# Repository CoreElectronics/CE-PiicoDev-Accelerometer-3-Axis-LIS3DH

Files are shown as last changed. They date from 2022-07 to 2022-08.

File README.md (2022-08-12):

# PiicoDev® Acceleromter LIS3DH

This is the repo for the Core Electronics [PiicoDev Accelerometer LIS3DH](https://core-electronics.com.au/catalog/product/view/sku/CE08705).
(https://core-electronics.com.au/catalog/product/view/sku/CE08705)

## License
This project is open source - please review the LICENSE.md file for further licensing information.

If you have any technical questions, or concerns about licensing, please contact technical support on the [Core Electronics forums](https://forum.core-electronics.com.au/).

*\"PiicoDev\" and the PiicoDev logo are trademarks of Core Electronics Pty Ltd.*

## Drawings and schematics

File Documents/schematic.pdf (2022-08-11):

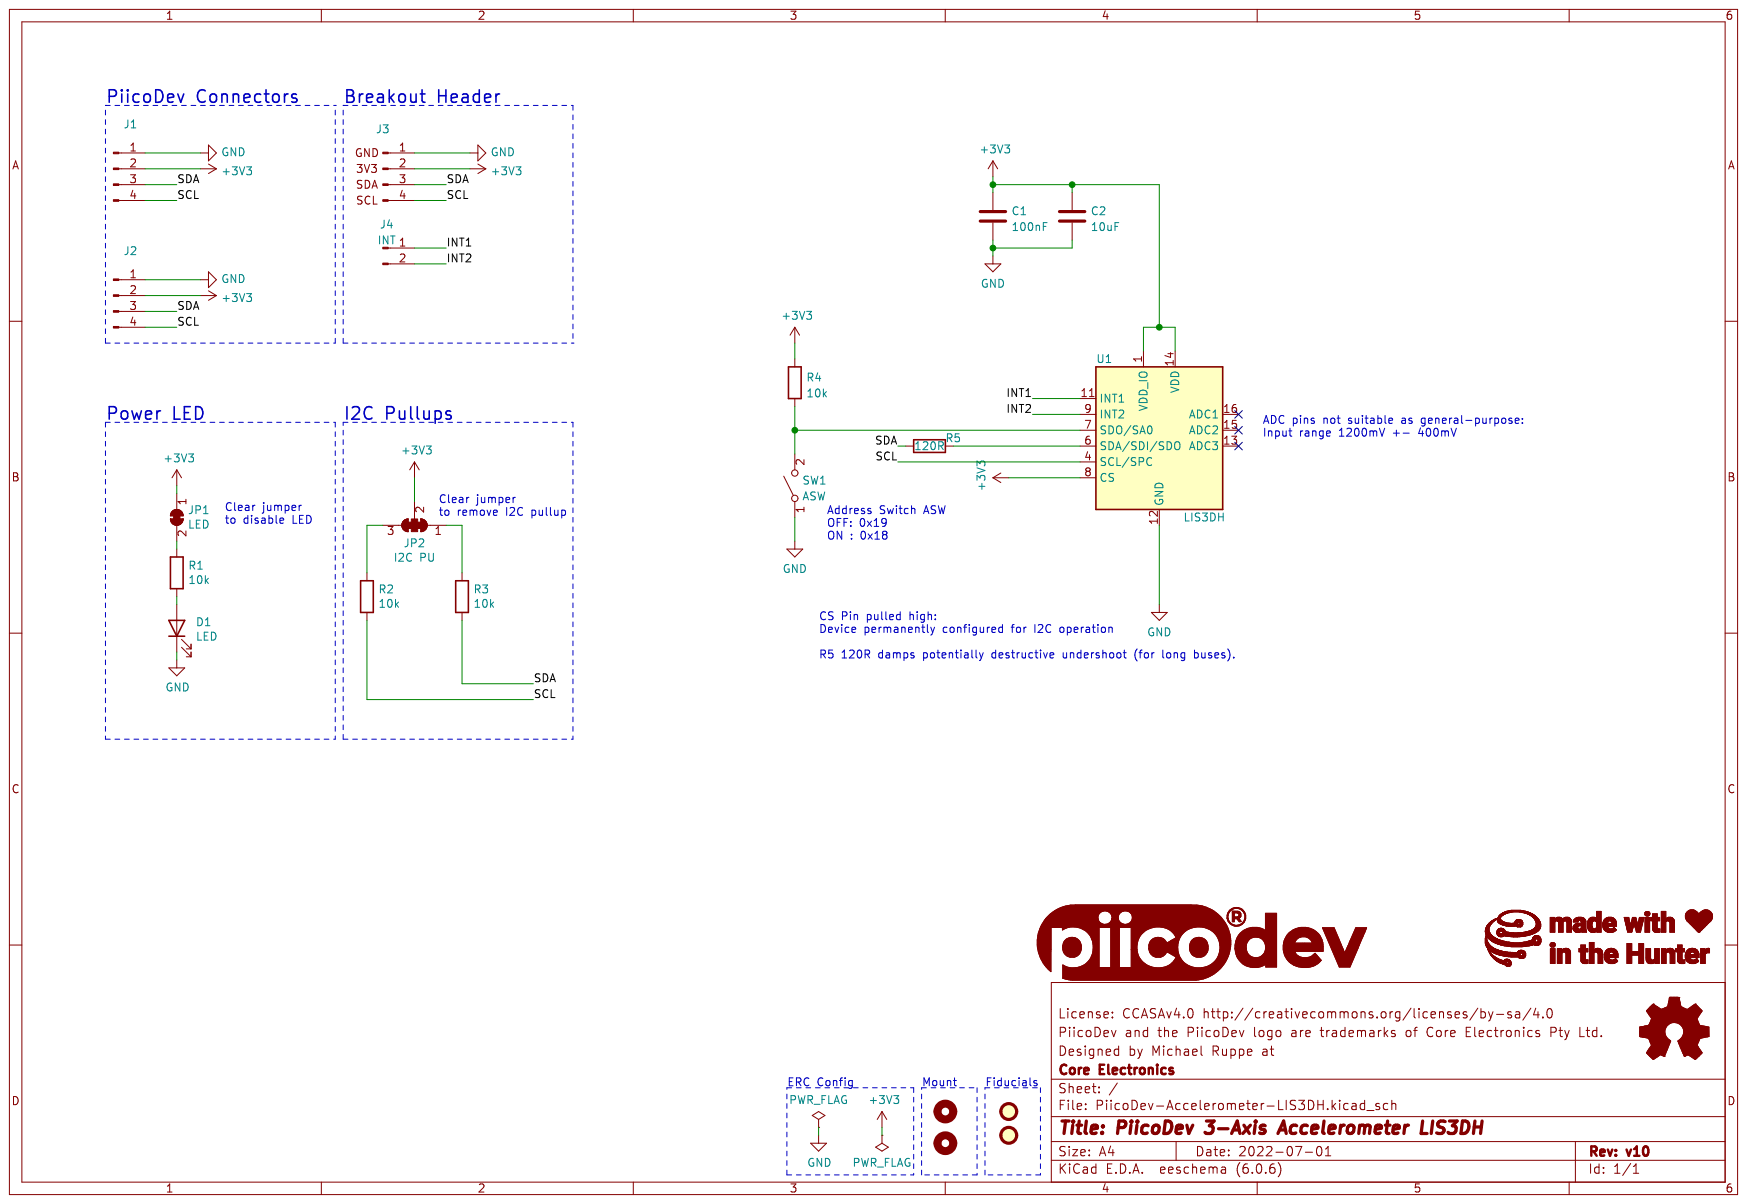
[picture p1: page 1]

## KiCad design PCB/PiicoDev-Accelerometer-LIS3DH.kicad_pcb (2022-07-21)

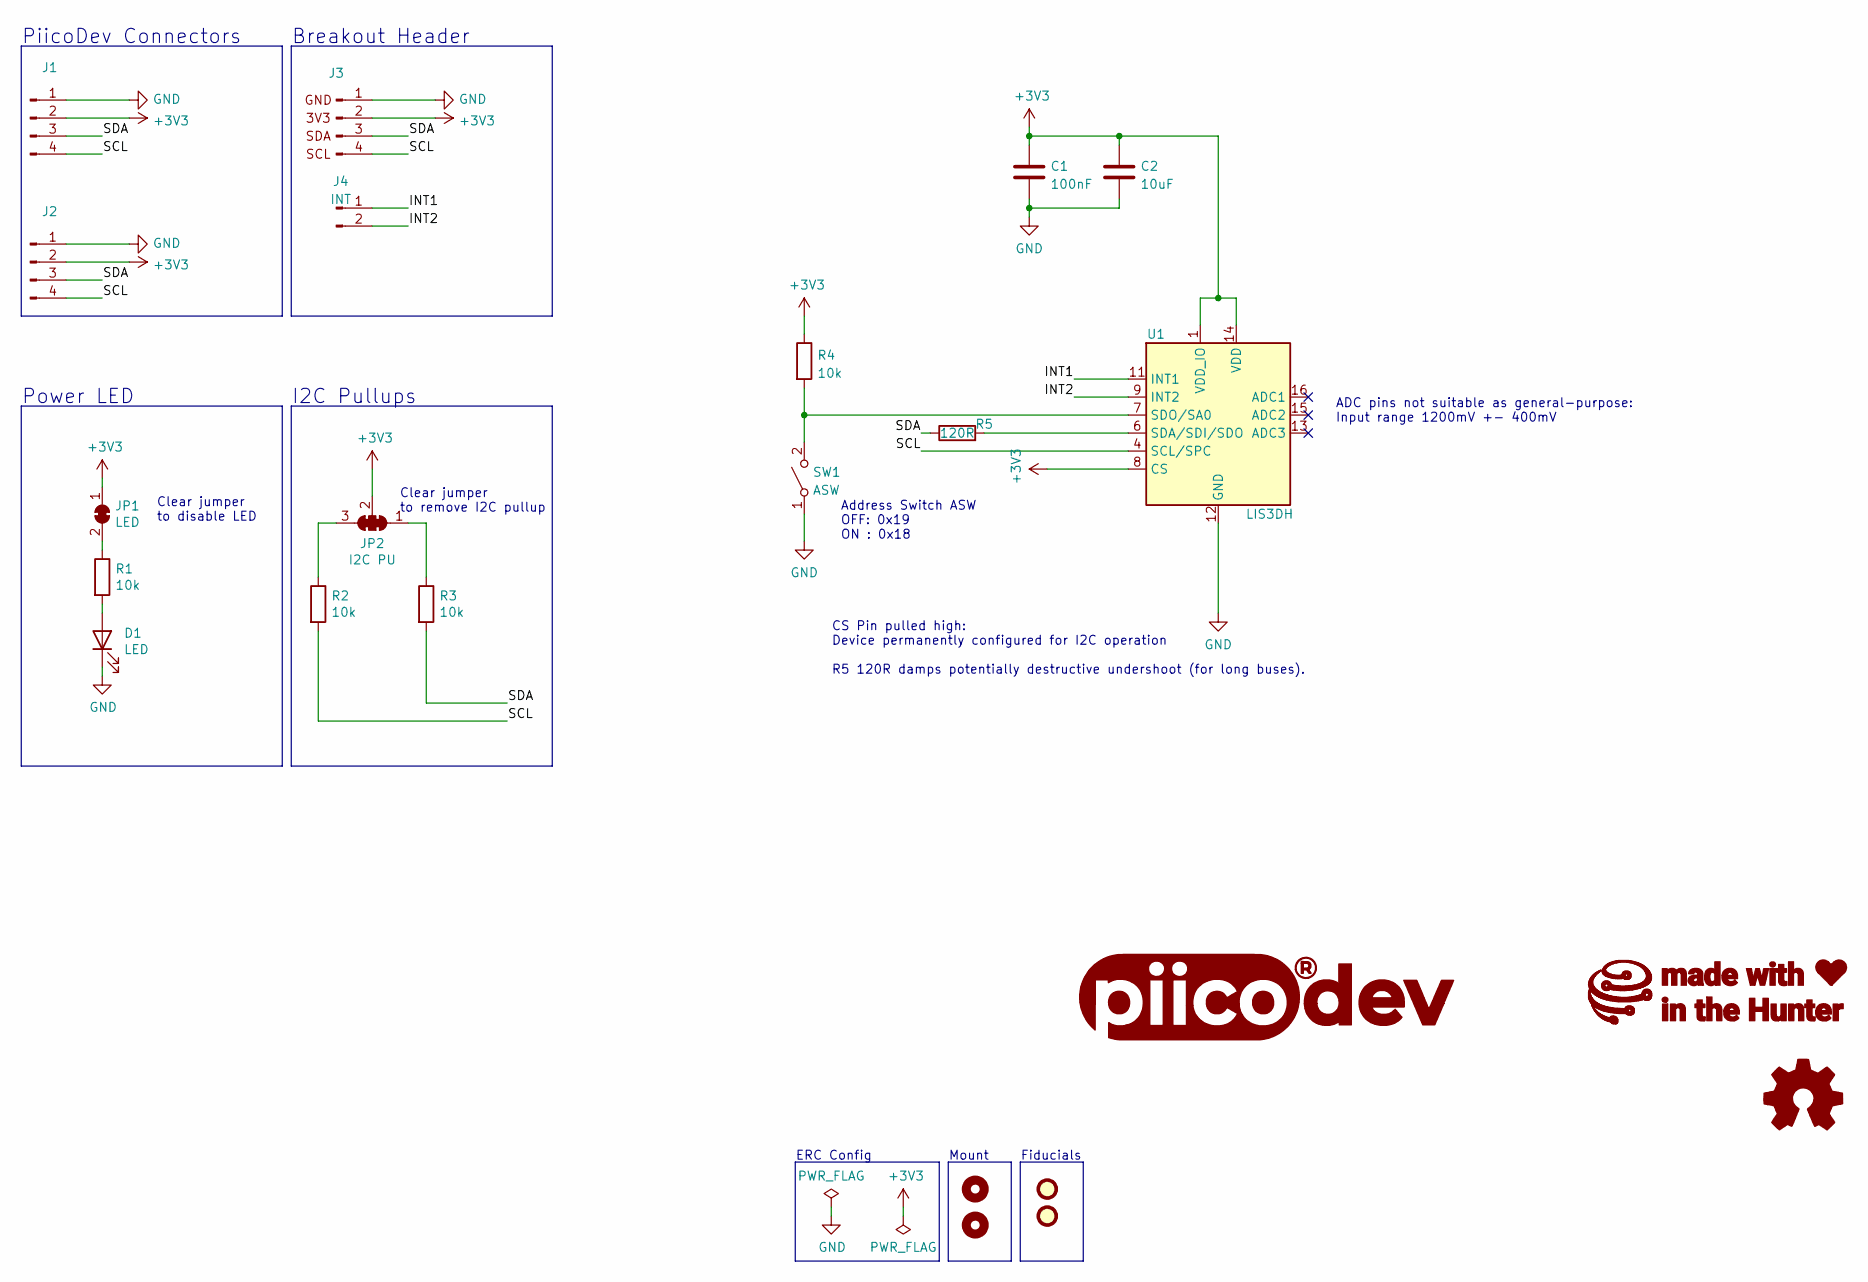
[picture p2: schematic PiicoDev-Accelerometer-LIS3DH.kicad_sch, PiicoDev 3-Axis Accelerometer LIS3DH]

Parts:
C1: 100nF; C_0402_1005Metric
C2: 10uF; C_0603_1608Metric
D1: LED; LED_0603_1608Metric
FID1, FID2: Fiducial; Fiducial_1mm_Mask2mm
G1: LOGO_PiicoDev; piicodev_logo_14.2x3.4mm
G2: LOGO_CoreElectronics_no-text; CoreElectronics_logo_5mm
G3: LOGO_made-with-love; piicodev_logo_14.2x3.4mm
H1, H2: MountingHole; MountingHole_2.7mm_M2.5_PadClearance_1.2
J1, J2: JST_SH_SM04B-SRSS-TB_1x04-1MP_P1.00mm_Horizontal
J3: Conn_PiicoDev_header_01x04_Male; PiicoDev_header_4pin
J4: INT; PinHeader_1x02_P2.54mm_Vertical
JP1: LED; SolderJumper-2_P1.3mm_Bridged_RoundedPad1.0x1.5mm
JP2: I2C PU; SolderJumper-3_P1.3mm_Closed_RoundedPad1.0x1.5mm_NumberLabe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
LOGO1: Logo_Open_Hardware_Small; oshw
R1, R2, R3, R4: 10k; R_0402_1005Metric
R5: 120R; R_0402_1005Metric
SW1: ASW; SW_DIP_x01_Slide_CHS-01A1
U1: LIS3DH; LGA-16_3x3mm_P0.5mm_LayoutBorder3x5y

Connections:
+3V3: C1.1, C2.1, J1.2, J2.2, J3.2, JP1.1 (A), JP2.2 (C), R4.1, U1.1 (VDD_IO), U1.8 (CS), U1.14 (VDD)
/INT1: J4.1, U1.11 (INT1)
/INT2: J4.2, U1.9 (INT2)
/SCL: J1.4, J2.4, J3.4, R2.2, U1.4 (SCL/SPC)
/SDA: J1.3, J2.3, J3.3, R3.2, R5.1
GND: C1.2, C2.2, D1.1 (K), J1.1, J2.1, J3.1, SW1.1 (A), U1.5 (GND), U1.10 (GND), U1.12 (GND)
unnamed: D1.2 (A), R1.2
unnamed: JP1.2 (B), R1.1
unnamed: JP2.1 (A), R3.1
unnamed: JP2.3 (B), R2.1
unnamed: R4.2, SW1.2 (B), U1.7 (SDO/SA0)
unnamed: R5.2, U1.6 (SDA/SDI/SDO)

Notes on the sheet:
Breakout Header
Address Switch ASW OFF: 0x19 ON : 0x18
Fiducials
I2C Pullups
CS Pin pulled high: Device permanently configured for I2C operation R5 120R damps potentially destructive undershoot (for long buses).
Clear jumper to remove I2C pullup
ERC Config
ADC pins not suitable as general-purpose: Input range 1200mV +- 400mV
Power LED
Clear jumper to disable LED
Mount
PiicoDev Connectors

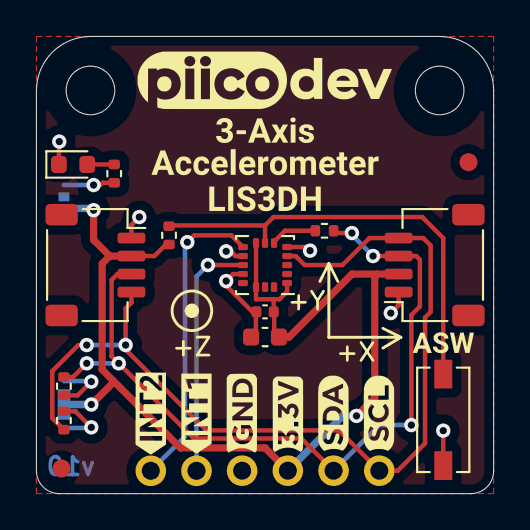
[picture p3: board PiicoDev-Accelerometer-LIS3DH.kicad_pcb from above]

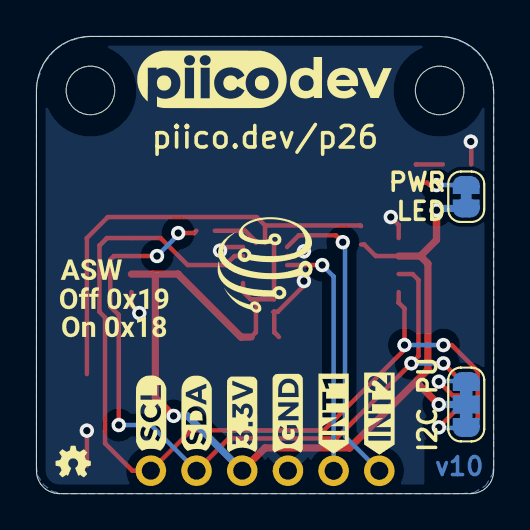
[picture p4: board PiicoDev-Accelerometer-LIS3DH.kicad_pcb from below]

Board: 2 copper layers, 25.4 x 25.4 mm, 38 parts (11 on the bottom side), 12 nets.

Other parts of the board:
Ref**: Axes_and_polarity_Y
Ref**#2: Axes_and_polarity_Z
Ref**#3: Axes_and_polarity_X
kibuzzard-62B3F7CF: G***; kibuzzard-62B3F7CF
kibuzzard-62B3F7FD: G***; kibuzzard-62B3F7FD
kibuzzard-62B3F9C2, kibuzzard-62B3F9C2#2: G***; kibuzzard-62B3F9C2
kibuzzard-62B3F9DB, kibuzzard-62B3F9DB#2: G***; kibuzzard-62B3F9DB
kibuzzard-62B3F80B: G***; kibuzzard-62B3F80B
kibuzzard-62B3F81B: G***; kibuzzard-62B3F81B
kibuzzard-62B4082B: G***; kibuzzard-62B4082B
kibuzzard-62B4083B: G***; kibuzzard-62B4083B
kibuzzard-62B40846: G***; kibuzzard-62B40846

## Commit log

2022-06-23 Initial Commit v00 prototype
    [PiicoDev-Accelerometer-LIS3DH.kicad_pcb, PiicoDev-Accelerometer-LIS3DH.kicad_sch]
2022-07-21 add documents and link CAD
    [PiicoDev-Accelerometer-LIS3DH.kicad_pcb, PiicoDev-Accelerometer-LIS3DH.kicad_sch]
2022-08-11 add schematic.pdf

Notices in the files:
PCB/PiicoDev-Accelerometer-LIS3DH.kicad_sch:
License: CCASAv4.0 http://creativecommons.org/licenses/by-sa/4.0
